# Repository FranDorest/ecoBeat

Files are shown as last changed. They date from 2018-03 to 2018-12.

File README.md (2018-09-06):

# EndeF-ecoBeat
EcoBeat is a device that measures the energy consumption by means of pulses. These pulses are generated by measuring equipment such as electricity, water or gas meters. EcoBeat translates the pulses to the corresponding units and transmits them via WIFI to a server on the Internet. This device complies with the Internet of Things standards and is specially designed to make energy measurements

# cable connection

## Optical pulse
- The pulse happens when the Interruption(6) is conected to  VCC(2)
- Interruption(6) -> pulldown

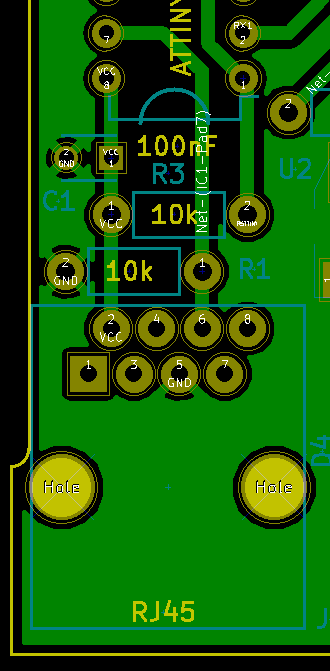
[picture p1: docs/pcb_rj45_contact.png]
pcb


## Mechanical pulse
- The pulse happens when the Interruption(6) is conected to GND(5) 
- Interruption(6) -> pullup

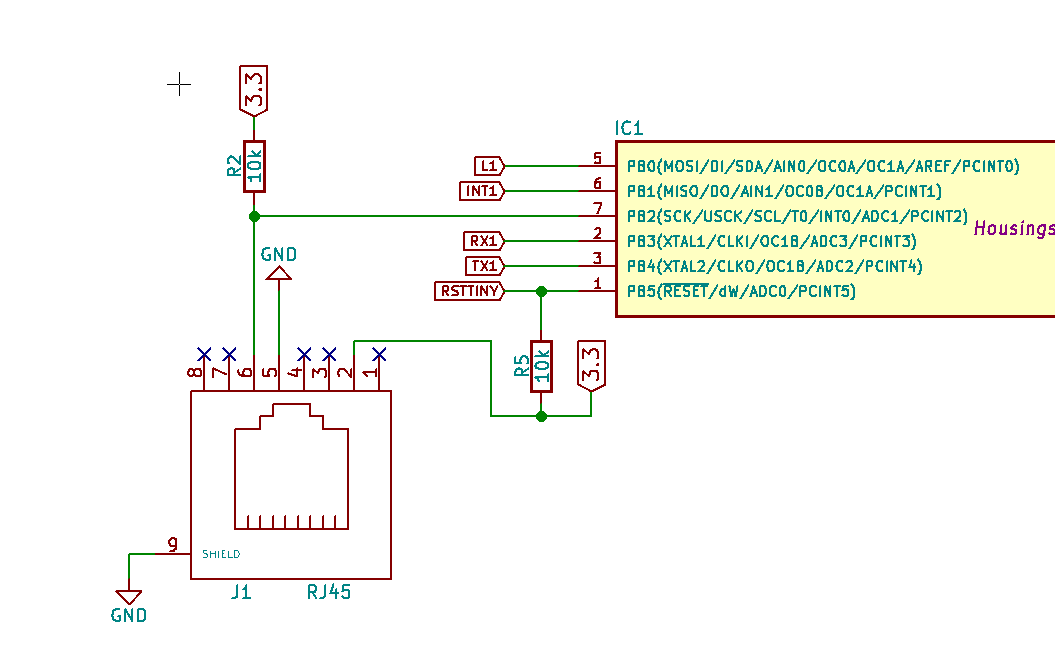
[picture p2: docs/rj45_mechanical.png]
schema


## PCB Modification 
- 10K is disconected from GND and conected to Vcc

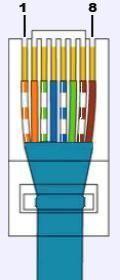
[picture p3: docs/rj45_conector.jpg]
cable


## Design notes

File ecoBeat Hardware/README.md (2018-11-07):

# PCB ecoBeat 3

Se ha creado una nueva PCB que se adapta a las medidas de una caja de montaje en carril DIN.

### Materiales

A continuación aparecen los materiales que se necesitarán para construir la placa *ecoBeat*.

* [Soldador] 
* [Estaño]
* [Pinzas]
* [ESP 12 F](https://www.elecrow.com/download/ESP-12F.pdf) - Microcontrolador de 32-bit 
* [ATtiny 85](http://www.farnell.com/datasheets/1698186.pdf) - Microcontrolador de 8-bit
* [LM1117 3.3v](http://www.ti.com/lit/ds/symlink/lm1117.pdf) - Regulador de voltaje 15v - 3.3v 800mA
* [RJ45 8P8P Female](https://es.rs-online.com/web/p/conectores-rj45/2578814/) - Conector RJ45
* [2x Pulsador](https://www.adafruit.com/product/367) - Pulsador 6x6mm
* [4x 10k R](https://es.rs-online.com/web/p/resistencias-fijas-de-orificio-pasante/7077745/) - Resistencia 10k 1/4W
* [3x 220 R](https://es.rs-online.com/web/p/resistencias-fijas-de-orificio-pasante/7077612/) - Resistencia 220 1/4W
* [1x 12k R](https://es.rs-online.com/web/p/resistencias-fijas-de-orificio-pasante/7077735/) - Resistencia 12k 1/4W
* [1x 6.8k R](https://es.rs-online.com/web/p/resistencias-fijas-de-orificio-pasante/7077735/) - Resistencia 6.8k 1/4W
* [2x 10uF C](https://es.rs-online.com/web/p/condensadores-de-aluminio/0117035/) - Condensador electrolítico 10uF 50v
* [1x 100nF C](https://es.rs-online.com/web/p/condensadores-ceramicos-multicapa/5373707/) - Condensador cerámico 100nF 50v
* [1x Diodo](https://es.rs-online.com/web/p/products/7965985/?tpr=1) - Diodo 1A
* [3x LED](https://es.rs-online.com/web/p/led-visibles/2285944/) - LED 3mm
* [Pin macho 2.54mm](https://es.rs-online.com/web/p/conectores-macho-para-pcb/5473166/) - Tira pin Macho 2.54mm
* [Pin macho 2mm](https://es.rs-online.com/web/p/conectores-macho-para-pcb/6813293/) - Tira pin Macho 2mm
* [Pin hembra 2mm](https://es.rs-online.com/web/p/conectores-hembra-para-pcb/6058774/) - Tira pin hembra 2mm

### Montaje

*

## Herramientas

* [KiCad 4.0.2](http://kicad-pcb.org/) - Diseño electrónico

## Consumos

*Se ha realizado una prueba para conocer los consumos del equipo en todos sus modos de trabajo en su versión de 5V.

Modo | Con LEDs | Sin LEDs | Un
--- | --- | --- | ---
AP | 87 - 88 | 85-86 | mA 
--- | --- | --- | ---
STA + AP | 87 - 88 | 85-86 | mA
--- | --- | --- | ---
STA |85.5 - 86.5 | 3.5 - 84.5 | mA
--- | --- | --- | ---
Transmisión | 86.5 - 87.5 | 84.5 - 85.5 | mA

*Vmax 12V. El regulador se calentará hasta los 65ºC y consumirá 84,5mA.

## Autores

* **Francisco Doreste** 
* **Oscar Pujal** 

## Licencia

Este proyecto se encuentra bajo licencia GPL.

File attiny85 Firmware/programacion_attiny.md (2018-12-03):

# Objetivo

En este documento se indica como cargar correctamente el Firmware al ATtiny 85 para el equipo ecoBeat.

El microcontrolador ATtiny 85 se encarga de contabilizar los impulsos emitidos por la sonda óptica de Open Energy Monitor y transmitirlos mediante comunicación serie al ESP8266. Esta medida de impulsos se utilizará en el servidor Open Energy Monitor para calcular el consumo de energía total y la potencia instantánea de su instalación.

## HERRAMIENTAS Y COMPONENTES
Para poder cargar el firmware a un ATtiny85, necesitará los siguientes componentes:

 - Arduino UNO 
 -  ATtiny85 
 - Placa de prototipado
 - Condensador electrolítico 10uF/25v
 - Cables dupont macho macho
 - Cable USB

> **Nota:** Podrá adquirir los componentes necesarios en la mayoría de tiendas físicas de componentes electrónicos o en internet.

## CONFIGURAR ARDUINO

Para utilizar el Arduino UNO como un programador de microcontroladores Atmel necesitamos configurarlo como un programador ISP (in-system-programming). Para ello el IDE de Arduino nos facilita el código que hace esto posible y se encuentra dentro de la carpeta de ejemplos bajo el nombre de **ArduinoISP. File -> Examples -> ArduinoISP**. 

Una vez abierto el ejemplo conectamos el Arduino uno al ordenador mediante el cable usb, seleccionamos en el Arduino IDE el tipo de placa correcta (Arduino/Genuino UNO) y el puerto serie correspondiente y cargamos el sketch.

> **Nota:** El nombre del Puerto serie dependerá del SO que use, pudiendo ser COMX en Windows o /tty/USBX en sistemas operativos en base Linux.

## SOPORTE ATTINY

Arduino IDE no soporta el microcontrolador ATtiny85 por defecto, así que debemos añadirlo manualmente. Para ello accedemos a las preferencias de **Arduino IDE en File -> preferences** y añadimos la siguiente URL a **Additional Boards Manager URLs..**

    https://raw.githubusercontent.com/damellis/attiny/ide-1.6.x-boardsmanager/package_damellis_attiny_index.json

Después de aceptar la nueva configuración debemos añadir el controlador a la librería de placas. Para ello
accedemos a **Tools -> Board -> Boards Manager…** y buscamos el paquete **“attiny by Davis A. Mellis”**. Lo seleccionamos e instalamos.
Después de esto debería ser capaz de encontrar dentro de **Tools -> Board** una opción llamada **Attiny**, que nos indica que la instalación se ha completado correctamente. Puede añadir más URLs de otras librerías separando las direcciones con comas.

## CONECTAR ARDUINO Y ATTINY
Una vez se haya completado la configuración anterior podemos conectar el ATtiny85 al Arduino UNO para empezar a programarlo. Para ello debemos montar el siguiente circuito teniendo en cuenta la posición del ATtiny.

| Arduino UNO | ATtiny85 |
|--|--|
| 5v | PIN 5 |
| GND | PIN4 |
| PIN 13 | PIN 6 |
| PIN 12 | PIN 7 |
| PIN 11 | PIN 8 |
| PIN 10 | PIN 1 |

> **Nota:** Añadiendo un condensador electrolítico de 10uF entre RESET y GND en el Arduino UNO evita que se produzca un RESET mientras cargamos el Firmware al ATtiny85.

>**Nota:** -Un circulo sobre el microcontrolador marca la posición del pin 1.

## CARGAR EL CÓDIGO AL ATTINY

Volviendo al Arduino IDE, seleccionamos en **Tools -> Board** la opción ATtiny25/45/85, en **Tools -> Processor** la opción ATtiny85, en **Tools -> Clock** Internal 8mHz, el puerto serie correspondiente y clicamos en **Burn Bootloader** . Si la carga se ha realizado correctamente podremos ver en la parte inferior del IDE **Done burning bootloader**. (La carga del bootloader no debe tardar más de 1 minuto). Una vez cargado podemos abrir la última versión del Firmware para el equipo ecoBeat bajo el nombre de **Firmware_ATtiny85_x.h** en la carpeta del proyecto y cargarlo normalmente con la misma configuración que usamos antes.

>**Nota:** Si observa falsas lecturas en el equipo puede incrementar el tiempo entre lecturas aumentando el valor de la constante **DEBOUNCE** en el código.
>
## COMPROBAR LA CARGA

Para asegurarnos de que todo el proceso ha sido realizado correctamente podemos montar el ATtiny85 ya
programado en el zócalo de 8 pines de la placa terminada del equipo ecoBeat y conectarle la sonda óptica de Open Energy monitor. Una vez montado debemos conectar el equipo a la fuente de alimentación y apuntar la sonda a una fuente de luz tenue. Al pasar la mano repetidas veces sobre la sonda deberíamos poder ver el led imp del equipo parpadear, confirmando que se ha realizado la carga con éxito.

>**Nota:** Si el led imp del equipo no parpadea debemos repetir las instrucciones desde el punto 5. Si esto no soluciona el problema póngase en contacto con nosotros.

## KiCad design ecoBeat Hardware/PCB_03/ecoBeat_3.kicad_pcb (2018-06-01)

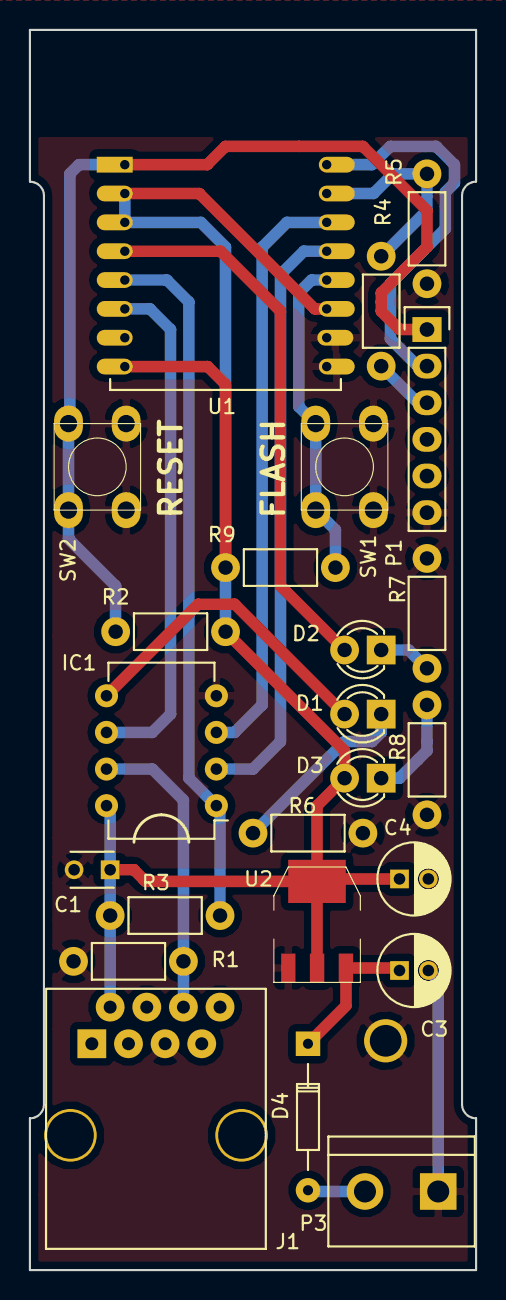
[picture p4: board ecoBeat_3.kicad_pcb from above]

Board: 2 copper layers, 30.9 x 86.0 mm, 24 parts (0 on the bottom side), 19 nets.

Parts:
C1: 100nF; C_Disc_D3_P2.5
C3, C4: 10uF; C_Radial_D5_L11_P2
D1, D2, D3: LED; LED-3MM
D4: D; Diode_DO-35_SOD27_Horizontal_RM10
IC1: ATTINY85-P; DIP-8_W7.62mm
J1: RJ45; RJ45_8
P1: CONN_01X06; Pin_Header_Straight_1x06
P3: CONN_01X02; bornier2
R1, R2, R3, R9: 10k; Resistor_Horizontal_RM7mm
R4: 6.8k; Resistor_Horizontal_RM7mm
R5: 12k; Resistor_Horizontal_RM7mm
R6, R7, R8: 220; Resistor_Horizontal_RM7mm
SW1, SW2: SW_PUSH; SW_PUSH_SMALL
U1: ESP-12E
U2: 1117; SOT-223

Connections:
ESPRST: P1.1, R2.2, SW2.1, U1.1
GND: C1.2, C3.2, C4.2, IC1.4, J1.5, P1.6, P3.1, R1.2, R5.1, R6.1, R7.1, R8.1, SW1.2, SW2.2, U1.9, U1.10, U2.1
INT1: IC1.6, U1.6
L1: D1.2, IC1.5
L2: D2.2, U1.4
unnamed: C3.1, D4.1, U2.3
unnamed: D1.1, R6.2
unnamed: D2.1, R7.2
unnamed: D3.1, R8.2
unnamed: D4.2, P3.2
unnamed: IC1.7, J1.6, R1.1
unnamed: P1.3, R4.1
unnamed: R9.1, SW1.1, U1.12
RSTTINY: IC1.1, R3.2, U1.5
RX1: IC1.2, U1.13
RXD: R4.2, R5.2, U1.15
TX1: IC1.3, U1.14
TXD: P1.2, U1.16
VCC: C1.1, C4.1, D3.2, IC1.8, J1.2, R2.1, R3.1, R9.2, U1.2, U1.3, U1.8, U1.11, U2.2

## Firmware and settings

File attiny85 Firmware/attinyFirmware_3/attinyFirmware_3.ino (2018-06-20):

#include <SoftwareSerial.h>

#define DEBOUNCE 10                     //ms minimos entre interrupciones para evitar rebotes

bool interruptEnabled = true;

unsigned long pulseCount = 0;             //Suma de Pulsos
unsigned long pulseAnterior = 0;          //pulsos anterior para calcular pulsos por minuto
unsigned long lastTime = 0;               // Diferencia de tiempo entre el ultimo envio y la comprobacion
unsigned long interruptTime = 0;          //Tiempo en el que se inicia la interrupcion
unsigned long long currentTime = 0;            //guarda el valor de millis()

SoftwareSerial atSerial(4,3);             //Comunicacion serie con ESP8266

void setup(){

  atSerial.begin(115200);                   // Comunicacion serie a 9600 baudios
  
  pinMode(0, OUTPUT);                     // Led de confirmacion de interrupcion
  pinMode(1, OUTPUT);                     // Pin de interrupcion al ESP8266

  attachInterrupt(0, onPulse, FALLING);   // Interrupcion en pin 2 (int 0) 
}

void loop(){
  
  if(millis() - interruptTime >= DEBOUNCE && !interruptEnabled){  //activamos interrupciones 10ms despues 
    interrupts();                                                 //de cada interrupcion para evitar rebotes.
    interruptEnabled = true;
  }
  
  if (millis() < lastTime){
    currentTime = lastTime + millis();
  }
  else{
    currentTime = millis();
  }
  
  if(currentTime - lastTime >= 60000){
    lastTime = millis();
    atSerial.print("imp_total:");
    atSerial.print(pulseCount);
    atSerial.print(",imp_min:");
    atSerial.println(pulseCount - pulseAnterior);
    pulseAnterior = pulseCount;
  }
}


void onPulse(){// Rutina de interrupcion
  noInterrupts();
  interruptTime = millis(); 
  interruptEnabled = false;
  pulseCount ++;
  digitalWrite(0, !digitalRead(0));
}

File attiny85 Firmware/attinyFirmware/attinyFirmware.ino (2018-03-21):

#include <SoftwareSerial.h>

SoftwareSerial atSerial(3,4); //Comunicacion serie con ESP8266 
long pulseCount = 0; //Numero de pulsos en 1 minuto
unsigned long lastTime = 0; 
unsigned long sendTime = 0; // Diferencia de tiempo entre el ultimo envio y la comprobacion

void setup(){
  atSerial.begin(9600); // Comunicacion serie a 115200 baudios
  pinMode(0, OUTPUT); // Led de confirmacion de interrupcion
  pinMode(1, OUTPUT); // Pin de interrupcion al ESP8266

  attachInterrupt(0, onPulse, RISING); // Interrupcion en pin 2 (int 0) 
}

void loop(){
}


void onPulse(){ // Rutina de interrupcion
  pulseCount ++;
  digitalWrite(0, !digitalRead(0));

  //enviamos la lectura una vez recibimos el pulso
  lastTime = millis();
  
  if(lastTime - sendTime >= 60000){ //Enviamos la cantidad de pulsos cada 60000 milisegundos (60segundos)
    noInterrupts();
    sendTime = lastTime;
    atSerial.println(pulseCount);
    pulseCount = 0;
    interrupts();
  }
}

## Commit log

2018-03-13 Board 2
    [ecoBeat_3.kicad_pcb, ecoBeat_3.sch]
2018-04-05 1117 volteado
    [ecoBeat_3.kicad_pcb]
2018-05-05 mandado a fabricar PCBWay
    [ecoBeat_3-B.Cu.gbr, ecoBeat_3-B.Mask.gbr, ecoBeat_3-B.SilkS.gbr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]
2018-05-25 firmware 2
    [ecoBeat_3.sch]
2018-06-01 lector de impulsos de contadores
    [ecoBeat_3.kicad_pcb, ecoBeat_3.sch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]
2018-06-14 attiny Firmware_3_actualizacion
    [ecoBeat_3.kicad_pcb, ecoBeat_3.sch]
2018-07-11 borrado hw para posteriormente mezclar
    [ecoBeat_3.kicad_pcb, ecoBeat_3.sch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]
2018-07-11 incluido sw de fabricacion
    [ecoBeat_3-B.Cu.gbr, ecoBeat_3-B.Mask.gbr, ecoBeat_3-B.SilkS.gbr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]
